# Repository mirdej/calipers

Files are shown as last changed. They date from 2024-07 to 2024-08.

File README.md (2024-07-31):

# Calipers

Bluetooth extension for cheap digital calipers.
An ESP32 reads data from the caliper serial port and "types" it as a BLE keyboard directly into the host computer.

## Arduino Library
The caliper-reading functions have been condensed into a simple class *Calipers* inside the file **Calipers.h**.
You can use the library as a standalone library for any Arduino (not only ESP32). 

[firmware/lib/Calipers](https://github.com/mirdej/calipers/tree/main/firmware/lib/Calipers) 

There are different scales and calipers out there with different protocols. See the readme of the library for more information.

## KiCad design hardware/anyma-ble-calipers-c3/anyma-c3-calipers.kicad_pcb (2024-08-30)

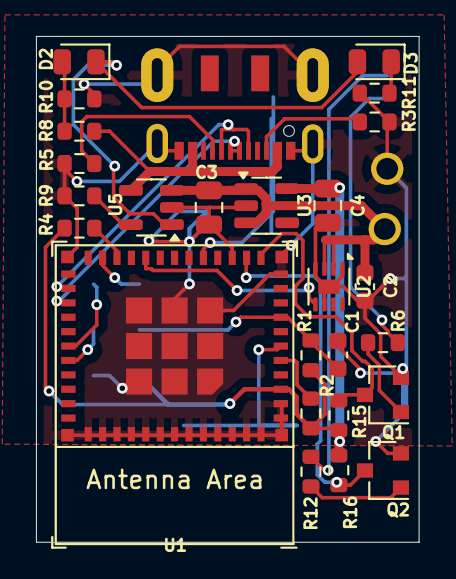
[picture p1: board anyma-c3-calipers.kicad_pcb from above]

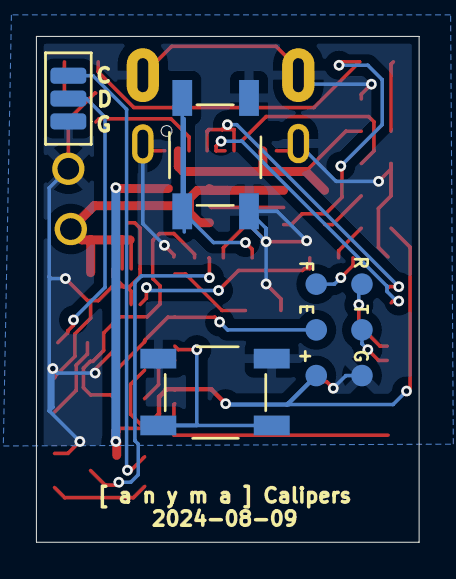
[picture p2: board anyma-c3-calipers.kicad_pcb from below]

Board: 2 copper layers, 21.3 x 28.1 mm, 32 parts (4 on the bottom side), 27 nets.

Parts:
C1: 1u; C_0603_1608Metric
C2: 100n; C_0603_1608Metric
C3: 10u; C_0805_2012Metric
C4: 4u7; C_0805_2012Metric
D2: CHRG; LED_0805_2012Metric
D3: RDY; LED_0805_2012Metric
J1: Conn_01x03_Pin; solderpad_1.27mm_3
J2: Prog; AnymaPOGO-ESP
J3: USB_C_Receptacle_USB2.0; JAE_USB-C_SJ122205
J9: BATT+; Solderpad_1mm
J10: BATT-; Solderpad_1mm
Q1, Q2: BC847; SOT-23_BEC
R1, R2, R3, R4, R5: 5k1; R_0603_1608Metric
R6, R12: 560; R_0603_1608Metric
R8, R9, R10, R11: 2k; R_0603_1608Metric
R15, R16: 51k; R_0603_1608Metric
SW2: Btn-1; Alps_Tactile_Switch
SW4: Btn-2; Alps_Tactile_Switch
U1: ESP32-C3-MINI-1
U2: TDFN-8-1EP_2x2mm_P0.5mm_EP0.8x1.2mm
U3: XC6220B331MR; SOT-23-5
U5: MCP73831-2-OT; SOT-23-5

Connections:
+3V3: C4.1, J2.1, R1.1, R2.1, R4.1, R15.2, R16.2, U1.3 (3V3), U3.5 (VOUT)
+5V: J3.A4 (VBUS), J3.A9 (VBUS), R8.1, U5.4 (VDD)
+BATT: C2.1, C3.1, J9.1, U2.2 (CELL), U2.3 (VDD), U3.1 (VIN), U3.3 (CE), U5.3 (VBAT)
/clock: J1.1, R12.1
/data: J1.2, R6.1
/en: C1.1, J2.2, R1.2, U1.8 (EN/CHIP_PU)
/flash: J2.3, U1.23 (GPIO9)
/gpio_0: Q1.C, R15.1, U1.12 (GPIO0/ADC1_CH0/XTAL_32K_P)
/gpio_1: Q2.C, R16.1, U1.13 (GPIO1/ADC1_CH1/XTAL_32K_N)
/gpio_6: U1.20 (GPIO6), U2.5 (!ALRT)
/rx: J2.4, U1.30 (GPIO20/U0RXD)
/strap1: R4.2, U1.22 (GPIO8)
/strap2: R2.2, U1.5 (GPIO2/ADC1_CH2)
/tx: J2.5, U1.31 (GPIO21/U0TXD)
/usb+: J3.A6 (D+), J3.B6 (D+), U1.27 (GPIO19/USB_D+)
/usb-: J3.A7 (D-), J3.B7 (D-), U1.26 (GPIO18/USB_D-)
GND: C1.2, C2.2, C3.2, C4.2, J1.3, J2.6, J3.A1 (GND), J3.A12 (GND), J3.S1 (SHIELD), J10.1, Q1.E, Q2.E, R3.2, R5.2, R9.2, R10.2, R11.2, SW2.2, SW4.2, U1.1 (GND), U1.2 (GND), U1.11 (GND), U1.14 (GND), U1.36 (GND), U1.37 (GND), U1.38 (GND), U1.39 (GND), U1.40 (GND), U1.41 (GND), U1.42 (GND), U1.43 (GND), U1.44 (GND), U1.45 (GND), U1.46 (GND), U1.47 (GND), U1.48 (GND), U1.49 (GND), U1.50 (GND), U1.51 (GND), U1.52 (GND), U1.53 (GND), U2.1 (CTG), U2.4 (GND), U2.6 (QSTRT), U2.9 (EP), U3.2 (GND), U5.2 (VSS)
unnamed: D2.2 (A), R8.2, R10.1
unnamed: D2.1 (K), D3.2 (A), U5.1 (STAT)
unnamed: D3.1 (K), R11.1
unnamed: J3.A5 (CC1), R3.1
unnamed: J3.B5 (CC2), R5.1
unnamed: Q1.B, R6.2
unnamed: Q2.B, R12.2
unnamed: SW4.1, U1.6 (GPIO3/ADC1_CH3)
unnamed: SW2.1, U1.16 (GPIO10)
unnamed: R9.1, U5.5 (PROG)

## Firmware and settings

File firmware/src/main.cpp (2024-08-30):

#include <Arduino.h>
#include <BleKeyboard.h>
#include "Calipers.h"
#include "SPI.h"

const int NUM_BTNS = 2;
const int PIN_CALIP_CLK = 1;
const int PIN_CALIP_DATA = 0;
const int PIN_BTN[NUM_BTNS] = {3, 10};

BleKeyboard bleKeyboard("Calipers", "[ a n y m a ]", 90);
Calipers caliper;

uint64_t button_pin_mask()
{
  uint64_t mask = 0;
  for (int i = 0; i < NUM_BTNS; i++)
  {
    mask |= (1 << PIN_BTN[i]);
  }
  return mask;
}

//----------------------------------------------------------------------------------------
//																				BUTTONS

void btn_task(void *)
{
  int state[NUM_BTNS];
  int old_state[NUM_BTNS];

  for (int i = 0; i < NUM_BTNS; i++)
  {
    pinMode(PIN_BTN[i], INPUT_PULLUP);
    old_state[i] = digitalRead(PIN_BTN[i]);
    log_v("Button %d initialised", i);
  }

  while (1)
  {
    for (int i = 0; i < NUM_BTNS; i++)
    {
      state[i] = digitalRead(PIN_BTN[i]);
      if (state[i] != old_state[i])
      {
        old_state[i] = state[i];
        if (!state[i])
        {
          log_v("Button %d pressed", i);
          char buf[10];
          float f = caliper.get_mm();

          if (bleKeyboard.isConnected())
          {

            // Weird Bug? prints ' instead of - on negative numbers (BLE only)
            if (f < 0.)
            {
              f = 0. - f;
              bleKeyboard.print('/'); // ASCII slash character turns into minus sign
            }

            switch (i)
            {
            case 0:

              sprintf(buf, "%.2f\n", f);
              Serial.print(buf);
              bleKeyboard.print(buf);
              break;

              // radius from diameter (for sketchup...)
            case 1:
              sprintf(buf, "%.2f\n", f / 2.);
              Serial.print(buf);
              bleKeyboard.print(buf);
              break;
            }
          }
        }
        else
        {
          log_v("Button %d released", i);
        }
      }
    }

    vTaskDelay(pdMS_TO_TICKS(100));
  }
}

void print_wakeup_reason()
{
  esp_sleep_wakeup_cause_t wakeup_reason;

  wakeup_reason = esp_sleep_get_wakeup_cause();

  switch (wakeup_reason)
  {
  case ESP_SLEEP_WAKEUP_EXT0:
    Serial.println("Wakeup caused by external signal using RTC_IO");
    break;
  case ESP_SLEEP_WAKEUP_EXT1:
    Serial.println("Wakeup caused by external signal using RTC_CNTL");
    break;
  case ESP_SLEEP_WAKEUP_TIMER:
    Serial.println("Wakeup caused by timer");
    break;
  case ESP_SLEEP_WAKEUP_TOUCHPAD:
    Serial.println("Wakeup caused by touchpad");
    break;
  case ESP_SLEEP_WAKEUP_ULP:
    Serial.println("Wakeup caused by ULP program");
    break;
  default:
    Serial.printf("Wakeup was not caused by deep sleep: %d\n", wakeup_reason);
    break;
  }
}

//========================================================================================
//----------------------------------------------------------------------------------------
//																				Loop

void setup()
{
  Serial.begin(115200);
  delay(1000);
  Serial.println(PROJECT_PATH);
  Serial.println(FIRMWARE_VERSION);

  print_wakeup_reason();

  log_v("Starting BLE");
  bleKeyboard.begin();

  caliper.begin(PIN_CALIP_DATA, PIN_CALIP_CLK);
 // esp_deep_sleep_enable_gpio_wakeup(button_pin_mask(), ESP_GPIO_WAKEUP_GPIO_LOW);
 esp_deep_sleep_enable_gpio_wakeup(1 << PIN_CALIP_CLK, ESP_GPIO_WAKEUP_GPIO_LOW);
  xTaskCreate(
      btn_task,  // Function that implements the task.
      "Buttons", // Text name for the task.
      8192,      // Stack size in words, not bytes.
      NULL,      // Parameter passed into the task.
      0,         // Priority at which the task is created.
      NULL);
}

//========================================================================================
//----------------------------------------------------------------------------------------
//																				Loop

void loop()
{
  if (!caliper.is_on())
  {
    Serial.print("Caliper is off");
    esp_deep_sleep_start();
    delay(1000);
    Serial.print("Caliper is still off");
  }

  if (caliper.available())
  {
    //  caliper.print(); // print debug info

    delay(2);
    // Serial.printf("Distance: %.2f\n",caliper.get_mm());
  }
  delay(4);
}

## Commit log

2024-07-31 compiles for other arduinos as well, not only esp32
2024-07-31 add pcb
    [anyma-c3-calipers.kicad_pcb, anyma-c3-calipers.kicad_sch]
2024-08-30 china hardware version
    [anyma-c3-calipers.kicad_pcb, anyma-c3-calipers.kicad_sch]
